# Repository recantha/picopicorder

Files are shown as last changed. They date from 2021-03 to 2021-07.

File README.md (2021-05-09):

# The PicoPicorder
The Picorder project, redux, on a Raspberry Pi Pico.

This project is based on the idea of the Star Trek "tricorder". It is a labour of love which has taken me through at least 10 versions of the same thing, in various different forms. [See this page for a history of the project](https://www.recantha.co.uk/blog/?cat=37).

The PicoPicorder is the latest iteration and is based on the Raspberry Pi Pico. [A full write-up can be found here](https://www.recantha.co.uk/blog/?page_id=20924).

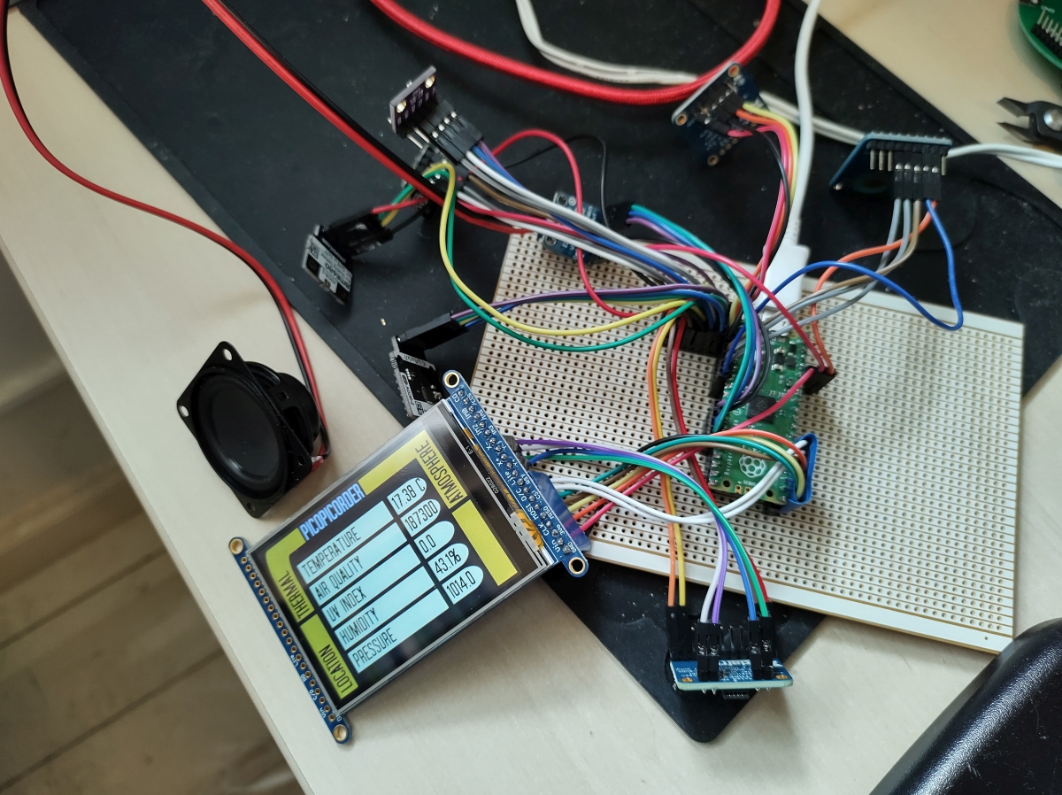
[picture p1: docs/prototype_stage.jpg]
Picture of the PicoPicorder as of 4-Apr-2021 PicoPicorder


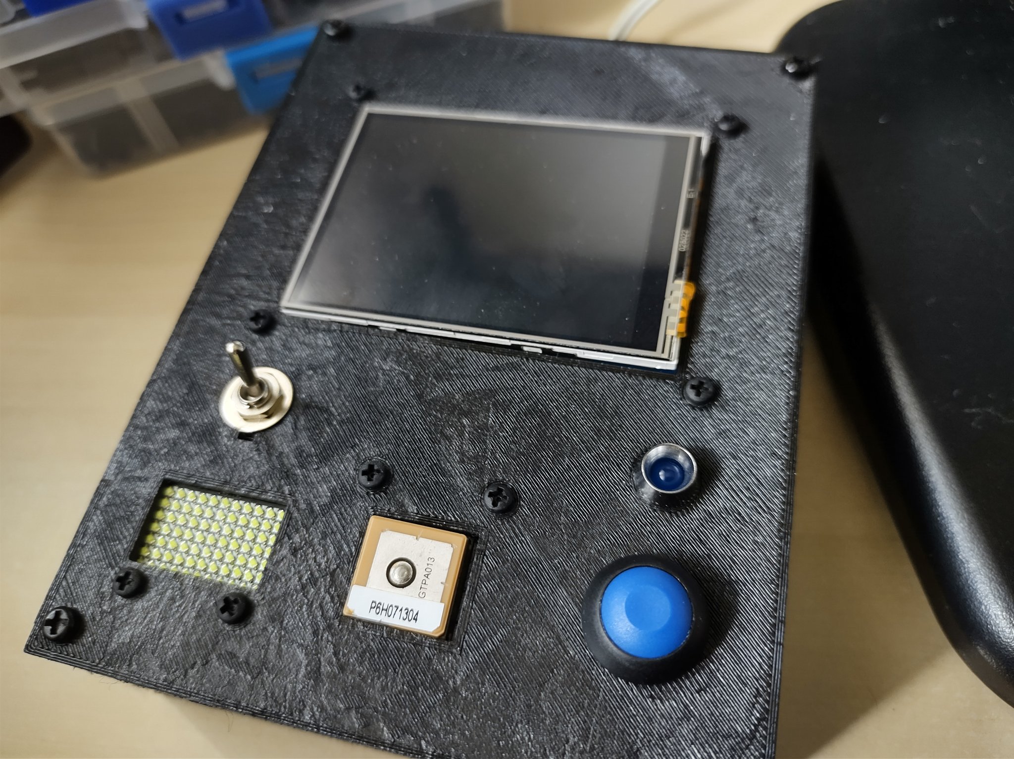
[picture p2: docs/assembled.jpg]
Picture of the PicoPicorder as of 9-May-2021 PicoPicorder


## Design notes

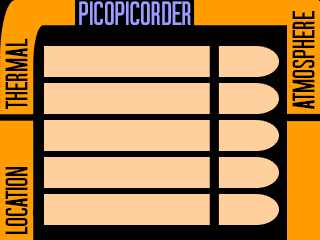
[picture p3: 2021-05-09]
img/Picorder graphic_dec.bmp

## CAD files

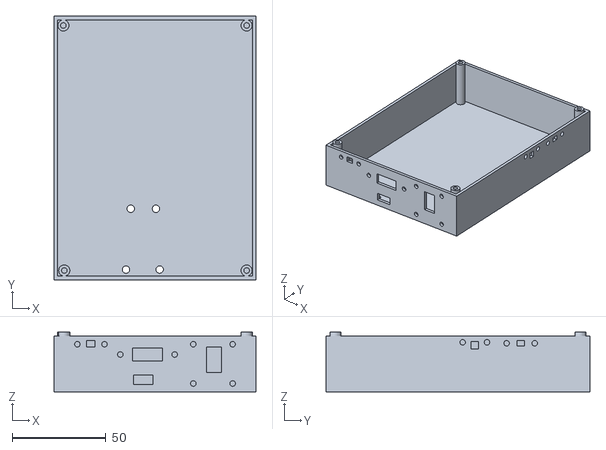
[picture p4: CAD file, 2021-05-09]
3d/PicoPicorder bottom (v2).stl
108.0 x 141.0 x 32.0

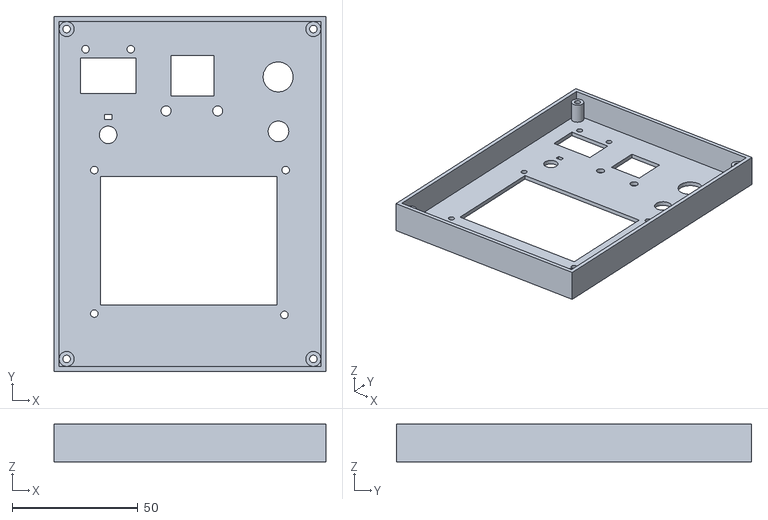
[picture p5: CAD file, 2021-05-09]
3d/PicoPicorder top (v2).stl
108.0 x 141.0 x 15.0

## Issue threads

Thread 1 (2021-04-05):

Audio is ropey

recantha, 2021-04-05:
As ropey as a very ropey thing. See if there's any solution to the problem caused by the "flash drive" being read from the laptop as well as being used to deliver the wav files to the I2S bus

recantha, 2021-05-09:
Decided to do without the audio due to case restrictions.

Closed 2021-05-09.

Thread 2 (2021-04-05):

Touchscreen unresponsive due to no interrupts and buffering

recantha, 2021-04-05:
As described here: https://www.recantha.co.uk/blog/?page_id=20924
The touchscreen (and this is the main flaw!) is extremely sluggish to register the touches. Now, to explain: CircuitPython does not have “interrupts”. So, I cannot just say “when there’s a touch, do something”, I have to keep on checking to see if there’s a touch each time around the main control loop. The trouble is, when the sensors are being interrogated, I can’t see the state of the touchscreen! So, for instance, on the first screen, you end up with:
Check touchscreen.
Check a sensor and output the sensor reading (x5)
Check touchscreen.
This means that I’m only checking the touchscreen once every half-to-three-quarter seconds. Unfortunately, the touchscreen chip also buffers the touches, so I’m checking the coordinates of the touch on the screen as it was when I touched it… that number of seconds ago. In the meantime, it’s buffered a good dozen or more readings. This could mean that I’m touching the bottom-right of the screen, but the code thinks I’m still touching top-left, like I was X seconds ago. Talk about frustrating!
Due to these factors, I might have to rewrite completely using MicroPython which does have interrupts! ARGH!

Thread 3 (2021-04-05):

The 8x8 thermal display is technically challenging

dglaude, 2021-04-05:
From watching your code yesterday, the way to display the 64 values is challenging and likely not optimal.
It created a lot of group and then fill them.
AFAIK for working a lot with thermal display, they most simple is to make a very small paletted bitmap, and scale it in displayio.
The palette would be you colour scale to translate temperature to colour and the bitmap will be exactly the size of what your sensor give you.
I do something similar with 32x24 MLS sensor: https://github.com/dglaude/CircuitPython_MLX90640_PyGamer_Plus

You may want to work on that.

I guess you have done that following a learn guide from Adafruit.
I know at least of one guide that does it that way, and maybe that is the only CP guide for that sensor.
Since I am working with another sensor I did not challenge that way of working.

recantha, 2021-04-05:
Thanks for the pointer, David. I'll take a look at your bitmap generation and see if I can figure out how to apply it :-)

dglaude, 2021-04-05:
I did spend some time on thermal camera "rendering", mostly working on the creation of a nice colour scale in a palette.
This is where having 64 colours is more fun that less.

My trick is to compute the min and max temperature of the sensor and then map to 64 colours.
The benefit is a better vision of the temperature variation, the negative is that red is not always the same color, so you have to help the user and display the min and max next to a color scale.

My code is on an array of 768 values (32*24) and finding the min/max or scaling those value was costly.
Recently I used ulab to do that part of the math and it goes faster.
Then a feature was added to Circuit Python to permit copy from an array directly to a bitmap too:

https://gist.github.com/dglaude/acb17b064a6554abdb5f07bcb59bbda5

There might need some adaptation needed, as the amg88 return a two dimentional array, but I guess ulab does support that too. I don't have your sensor, but I will see if I can fake it and write some matching code for doing what I did with my sensor.

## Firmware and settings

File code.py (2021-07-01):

import board
#import displayio
import sys
import time
from PicoPicorder import Picorder

# First of all, unlock the pins and buses related to the display(s)
picorder = Picorder(
    spi_clock=board.GP18,
    spi_mosi=board.GP19,
    spi_miso=board.GP16,
    i2c_scl=board.GP1,
    i2c_sda=board.GP0,
    dsp_command=board.GP21,
    dsp_chip_select=board.GP17,
    dsp_reset=board.GP20,
    i2s_clock=board.GP10,
    i2s_word=board.GP11,
    i2s_data=board.GP9,
    uart_tx=board.GP4,
    uart_rx=board.GP5
)

# Disable/enable touchscreen funcationality
touch_screen_enabled = False

# Initial mode
mode = 0

if mode == 0:
    picorder.displayLCARS("atmos")
    picorder.lcarsLabels("atmos")
elif mode == 1:
    picorder.thermal_camera.background()
elif mode == 2:
    picorder.displayLCARS("gps")
    picorder.lcarsLabels("gps")


print("Ready for input")

while True:
    try:
        '''
        if touch_screen_enabled:
            try:
                touch_x, touch_y, pressure = picorder.touch_screen.read_data()
                #print(str(touch_x) + ' ' + str(touch_y) + ' ' + str(pressure))

                if picorder.touch_screen.touched:
                    # When a touch is detected, we switch modes and do any 'set-up' required to go INTO the mode
                    if mode != 1 and (touch_x < 800 and touch_y > 3400):
                        mode = 1
                        picorder.playSound("snd_control_beep")
                        picorder.thermal_camera.background()

                    elif mode != 0 and (touch_x < 800 and touch_y < 800):
                        mode = 0
                        picorder.playSound("snd_engage_beep")
                        picorder.lcarsLabels("atmos")
                        picorder.displayLCARS("atmos")

                    elif mode !=2 and (touch_x > 2900 and touch_y > 3500):
                        mode = 2
                        picorder.playSound("snd_control_beep")
                        picorder.lcarsLabels("gps")
                        picorder.displayLCARS("gps")

                    else:
                        picorder.playSound("snd_tricorder")
                        print(str(mode) + " X:" + str(touch_x) + " / Y:" + str(touch_y))

            except Exception as err:
                print(str(err))
                pass

        else:
            pass
        '''

        if mode == 0:
            # display the LCARS interface
            picorder.displayLCARSreadings("atmos")

            if not picorder.button.value:
                #print("Change to 1")
                mode = 1
                picorder.matrix.flash()
                picorder.thermal_camera.background()

        elif mode == 1:
            picorder.thermal_camera.render()

            if not picorder.button.value:
                #print("Change to 2")
                mode = 2
                picorder.matrix.flash()
                picorder.displayLCARS("gps")
                picorder.lcarsLabels("gps")

        elif mode == 2:
            picorder.displayLCARSreadings("gps")

            if not picorder.button.value:
                #print("Change to 0")
                mode = 0
                picorder.matrix.flash()
                picorder.displayLCARS("atmos")
                picorder.lcarsLabels("atmos")

    except KeyboardInterrupt:
        sys.exit(1)

    except Exception as err:
        # Ignore all other errors except CTRL-C
        print(str(err))

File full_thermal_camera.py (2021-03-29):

# AMG8833 thermal camera on an ILI9341 320x240 screen
# Michael Horne, based on Jan Goolsbey's code for Adafruit
# https://learn.adafruit.com/pygamer-thermal-camera-amg8833?view=all

import time
import board
import displayio
import busio
from simpleio import map_range
from adafruit_display_text.label import Label
from adafruit_display_shapes.rect import Rect
import adafruit_amg88xx
import adafruit_ili9341

# Helper functions
def celsius_to_fahrenheit(deg_c=None):  # convert C to F; round to 1 degree C
    return round(((9 / 5) * deg_c) + 32)

def fahrenheit_to_celsius(deg_f=None):  # convert F to C; round to 1 degree F
    return round((deg_f - 32) * (5 / 9))

def element_grid(col0, row0):  # Determine display coordinates for column, row
    x = int(ELEMENT_SIZE * col0 + 30)  # x coord + margin
    y = int(ELEMENT_SIZE * row0 + 1)   # y coord + margin
    return x, y  # Return display coordinates

def update_image_frame():  # Get camera data and display
    minimum = MAX_SENSOR_C  # Set minimum to sensor's maximum C value
    maximum = MIN_SENSOR_C  # Set maximum to sensor's minimum C value

    sum_bucket = 0  # Clear bucket for building average value

    for row1 in range(0, 8):  # Parse camera data list and update display
        for col1 in range(0, 8):
            value = map_range(image[7 - row1][7 - col1],
                              MIN_SENSOR_C, MAX_SENSOR_C,
                              MIN_SENSOR_C, MAX_SENSOR_C)
            color_index = int(map_range(value, MIN_RANGE_C, MAX_RANGE_C, 0, 7))
            image_group[((row1 * 8) + col1) + 1].fill = element_color[color_index]
            sum_bucket = sum_bucket + value  # Calculate sum for average
            minimum = min(value, minimum)
            maximum = max(value, maximum)
    return minimum, maximum, sum_bucket

# Establish I2C interface for the AMG8833 Thermal Camera
i2c_scl = board.GP1
i2c_sda = board.GP0
i2c = busio.I2C(i2c_scl, i2c_sda)
amg8833 = adafruit_amg88xx.AMG88XX(i2c)

# The image sensor's design-limited temperature range
MIN_SENSOR_C = 0
MAX_SENSOR_C = 80
MIN_SENSOR_F = celsius_to_fahrenheit(MIN_SENSOR_C)
MAX_SENSOR_F = celsius_to_fahrenheit(MAX_SENSOR_C)

# Convert default alarm and min/max range values from config file
MIN_RANGE_F =  60
MAX_RANGE_F = 120
MIN_RANGE_C = fahrenheit_to_celsius(MIN_RANGE_F)
MAX_RANGE_C = fahrenheit_to_celsius(MAX_RANGE_F)

# The board's integral display size (as informed by product page adafru.it/1770)
WIDTH  = 320
HEIGHT = 240

ELEMENT_SIZE = WIDTH // 10  # Size of element_grid blocks in pixels

# Define colors
BLACK   = 0x000000
RED     = 0xFF0000
ORANGE  = 0xFF8811
YELLOW  = 0xFFFF00
GREEN   = 0x00FF00
CYAN    = 0x00FFFF
BLUE    = 0x0000FF
VIOLET  = 0x9900FF
WHITE   = 0xFFFFFF
GRAY    = 0x444455

# Block colors for the thermal image grid
element_color = [GRAY, BLUE, GREEN, YELLOW, ORANGE, RED, VIOLET, WHITE]

# Tell displayio to clean up after any previous usage
displayio.release_displays()

# Define ILI9341 screen as an SPI-interfaced display
tft_cs = board.GP17
tft_dc = board.GP21
tft_res = board.GP20
spi_mosi = board.GP19
spi_clk = board.GP18
spi_miso = board.GP16

spi = busio.SPI(clock=spi_clk, MOSI=spi_mosi, MISO=spi_miso)

display_bus = displayio.FourWire(spi, command=tft_dc, chip_select=tft_cs)
display = adafruit_ili9341.ILI9341(display_bus, width=WIDTH, height=HEIGHT)

# Initially, just show a bright green background to prove the display is working
splash = displayio.Group(max_size=10)
display.show(splash)

color_bitmap = displayio.Bitmap(320, 240, 1)
color_palette = displayio.Palette(1)
color_palette[0] = 0x00FF00  # Bright Green

bg_sprite = displayio.TileGrid(color_bitmap, pixel_shader=color_palette, x=0, y=0)

splash.append(bg_sprite)

# Draw a smaller inner rectangle
inner_bitmap = displayio.Bitmap(280, 200, 1)
inner_palette = displayio.Palette(1)
inner_palette[0] = 0xAA0088  # Purple
inner_sprite = displayio.TileGrid(inner_bitmap, pixel_shader=inner_palette, x=20, y=20)
splash.append(inner_sprite)

# Wait so it doesn't immediately get overwritten
time.sleep(1)

# Define the group for the thermal display
image_group = displayio.Group(max_size=77)
display.show(image_group)

# Create a black background color fill layer; image_group[0]
color_bitmap = displayio.Bitmap(WIDTH, HEIGHT, 1)
color_palette = displayio.Palette(1)
color_palette[0] = BLACK
background = displayio.TileGrid(color_bitmap, pixel_shader=color_palette, x=0, y=0)
image_group.append(background)

# Define the foundational thermal image element layers; image_group[1:64]
#   image_group[#]=(row * 8) + column
for row in range(0, 8):
    for col in range(0, 8):
        pos_x, pos_y = element_grid(col, row)
        # outline is normally None and stroke is 0
        element = Rect(x=pos_x, y=pos_y, width=ELEMENT_SIZE, height=ELEMENT_SIZE, fill=None, outline=None, stroke=0)
        image_group.append(element)

# Main loop
while True:
    image = amg8833.pixels  # Get camera data list
    v_min, v_max, v_sum = update_image_frame()

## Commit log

2021-03-30 Bit more on basic functionality. Started to create proper code.py. Did try and do it object-orientated by SPI wasn't getting cleaned up, so moved to more sequential execution
2021-04-02 Final commit before going down the Object Orientated rabbit hole
2021-04-03 More work on the main object, adding in GPS and switching screens. Also some work on the sound samples which were a BIT LOUD!
2021-04-05 Final CircuitPython prototype code. Add better README.md and a graphic to go with it.
2021-05-09 Add 3D model STL files for 9th May 2021. Needs respin, but we can do that later.
    [PicoPicorder bottom (v2).stl, PicoPicorder top (v2).stl]
2021-05-09 Add 'reverse' parameter to ThermalCamera as module is mounted upside down in PicoPicorder
    [PicoPicorder.py, ThermalCamera.py]
2021-07-01 Change the way the Thermal Camera / Sensor works. Now uses linear interpolation (cf David Glaude/Adafruit)
